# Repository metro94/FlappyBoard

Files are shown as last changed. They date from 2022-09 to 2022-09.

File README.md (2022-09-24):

[中文](README_zh.md) | English

# FlappyBoard

## Introduction

A minimum development board for CH32V203G6. The goal is simplicity, convenience and low-cost.

## 3D Rendering View

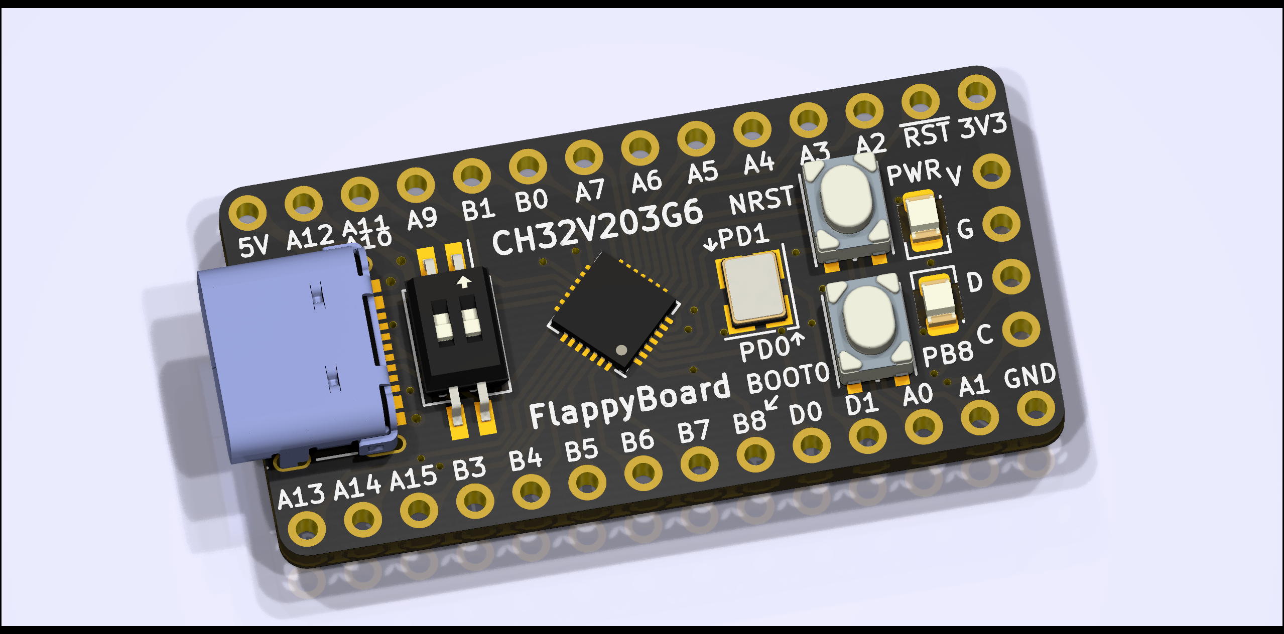
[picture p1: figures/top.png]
Top View


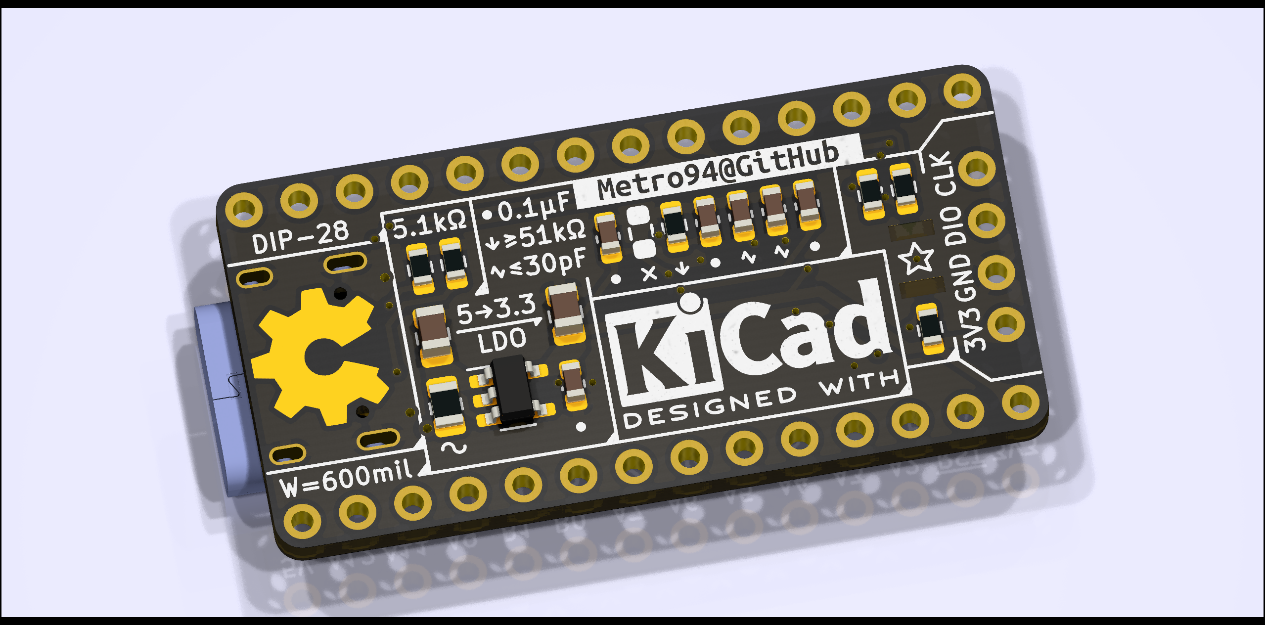
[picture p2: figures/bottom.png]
Bottom View


## License

[CERN-OHL-P](LICENSE)

## EDA

KiCad 6.0.6

## Usages

### Download Programs

It's simple and convenient to use USB download of [WCHISPTool](http://www.wch-ic.com/downloads/WCHISPTool_Setup_exe.html). Also serial download and debug port download is available.

WCHISTool requires correct MCU model (CH32V203) to download. The DIP switch shall be ON for downloading, and power the board with BOOT0 button pushed. If everything goes well, WCHISPTool shall report the MCU.

### LEDs and Buttons

There are two LEDs on the board, including *PWR* for power status (3.3V powered) and *PB8* for user-defined LED.

There are two buttons on the board, including *NRST* for system reset and *BOOT0* for boot mode (the default is to run user program in Flash, and push button to run bootloader in ROM).

> Note: In CH32V203G6, *PB8* and *BOOT0* is multiplexed. The behavior of this pin is:
>
> * When booting, MCU requires *BOOT0* status via this pin, and this pin is input. When *BOOT0* button is pushed, the LED of *PB8* is lighted to hint.
> * After entering user program, the *PB8* pin is available for output only, and the input value is invalid. Now, the LED of *PB8* can be controlled by user program, but the status of *BOOT0* button cannot be read.

### External Clock Input

CH32V203G6 can accept external oscillator and crystal. The valid frequency range is 3-25MHz.

### Schematics

[FlappyBoard Schematic](schematics/FlappyBoard.pdf)

### BOM

[FlappyBoard BOM](https://metro94.github.io/FlappyBoard/bom.html)

### Examples

[software/examples](software/examples)

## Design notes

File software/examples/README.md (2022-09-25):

# Examples for CH32V203G6

These examples are tested for FlappyBoard, and shall work for other CH32V203G6 boards.

> Note: WCHISPTool requires hex file to use CRLF as EOL.

*EVT* refers to [CH32V20xEVT.zip](https://www.wch.cn/downloads/CH32V20xEVT_ZIP.html), which contains source code of the most examples. [MounRiver Studio](http://www.mounriver.com/) or its toolchains can be used to compile source code.

> Note: These examples use *USART1* (*PA9*) as debug port with 115200n8 by default.

## CH372Device_D_FS

Compiled directly from `EVT/EXAM/USB/USBD/CH372Device`.

## CompositeKM

Modified from `EVT/EXAM/USB/USBD/CompositeKM`, use *PA2/PA3* as USART2 TX/RX.

## LED_Toggle

Modified from `EVT/EXAM/GPIO/GPIO_Toggle`, use PB8 LED and blink per 1 second.

## TinyMaix

TinyMaix demo for CH32V203G6. Please refer [CH32V203-TinyMaix](https://github.com/metro94/CH32V203-TinyMaix) or [TinyMaix](https://github.com/sipeed/TinyMaix) to get more information.

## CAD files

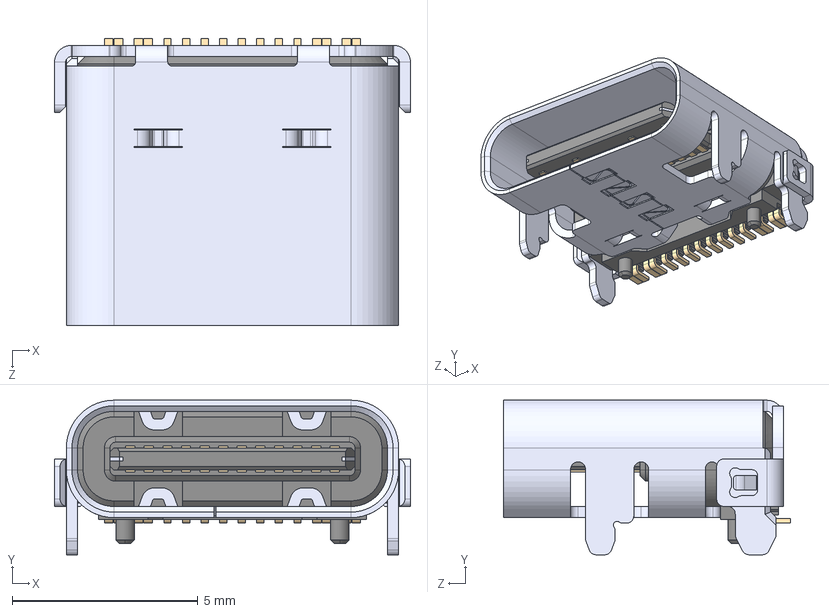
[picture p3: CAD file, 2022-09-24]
hardware/USB4105_GF_A.STEP
9.58 x 4.16 x 7.71 mm

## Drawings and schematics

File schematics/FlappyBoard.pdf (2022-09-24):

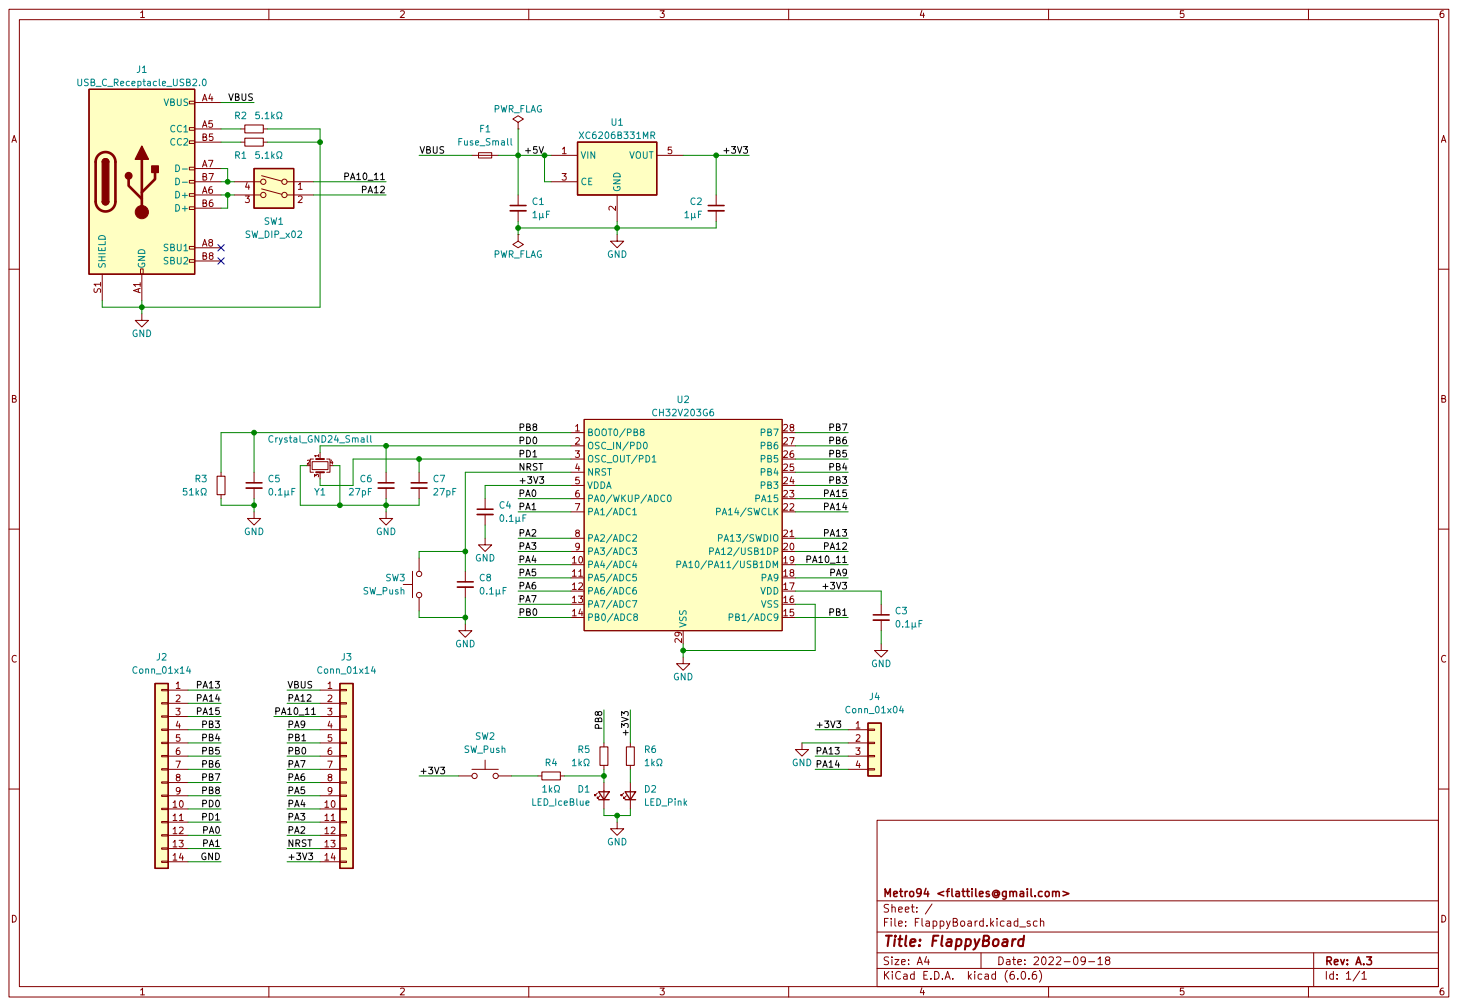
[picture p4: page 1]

File: FlappyBoard.kicad_sch Sheet: / Metro94 <flattiles@gmail.com>

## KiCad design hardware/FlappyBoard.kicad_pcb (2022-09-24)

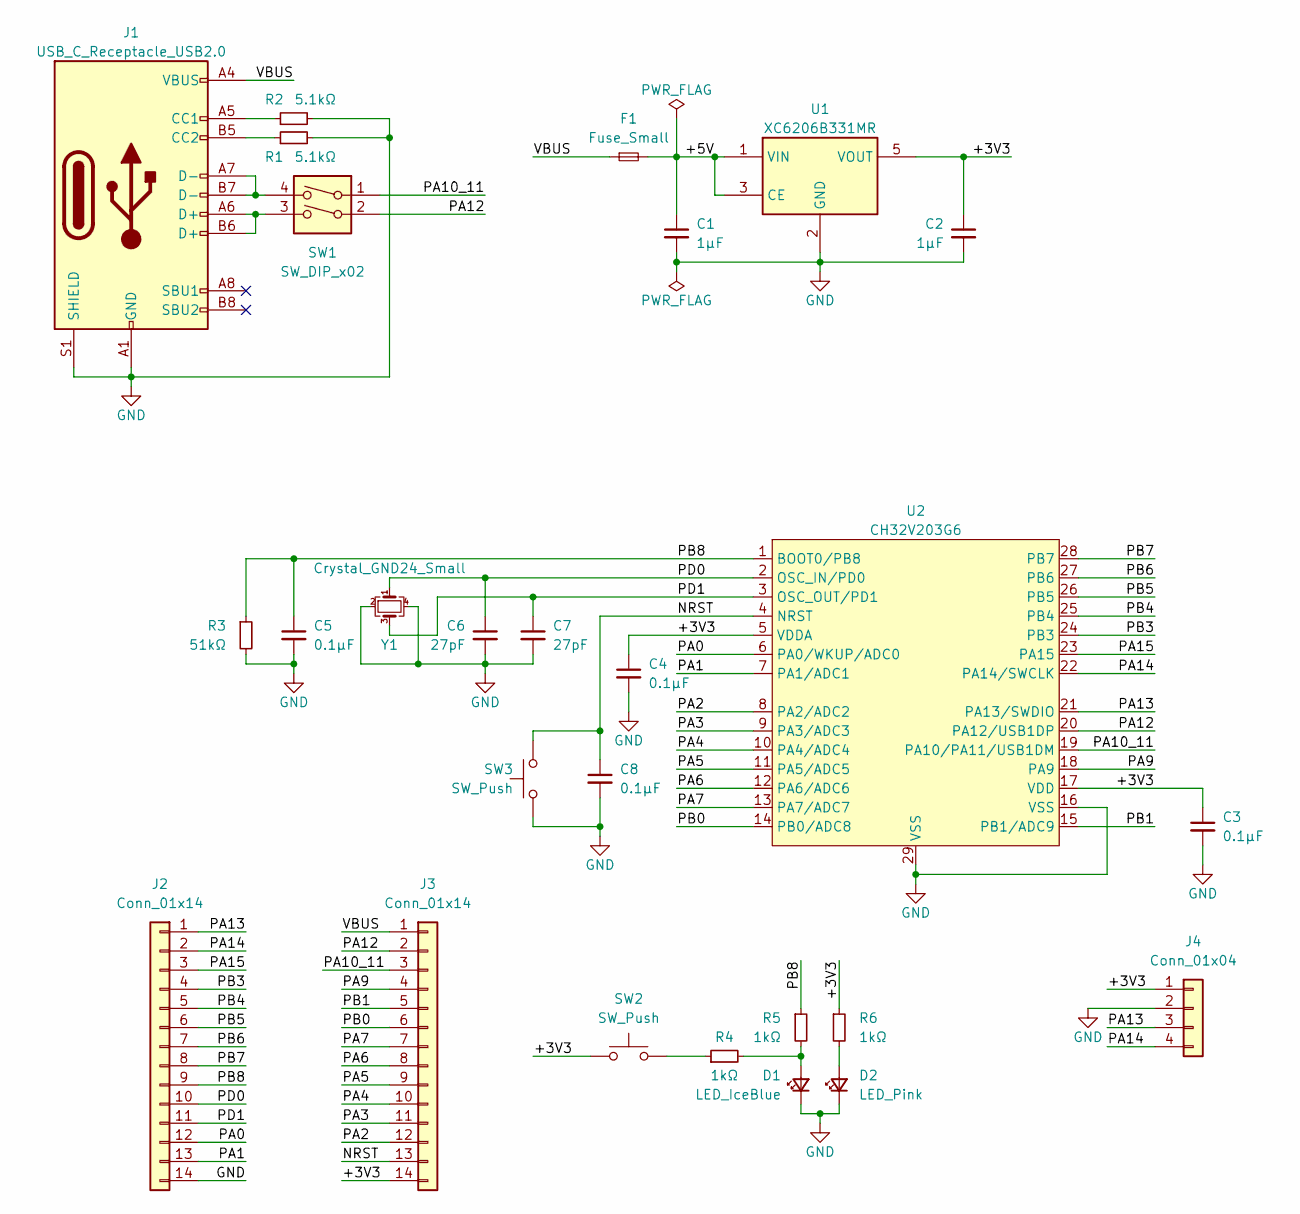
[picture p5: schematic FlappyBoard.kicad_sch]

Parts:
C1, C2: 1μF; C_0805_2012Metric; LCSC C28323
C3, C4, C5, C8: 0.1μF; C_0603_1608Metric; LCSC C14663
C6, C7: 27pF; C_0603_1608Metric
D1: LED_IceBlue; LED_0805_2012Metric; LCSC C2892177
D2: LED_Pink; LED_0805_2012Metric; LCSC C2892178
F1: Fuse_Small; Fuse_0805_2012Metric; LCSC C116170
J1: USB_C_Receptacle_USB2.0; USB_C_Receptacle_Palconn_UTC16-G; LCSC C963370
J2, J3: Conn_01x14; Pin_1x14_P2.54mm
J4: Conn_01x04; Pin_1x04_P2.54mm
R1, R2: 5.1kΩ; R_0603_1608Metric; LCSC C23186
R3: 51kΩ; R_0603_1608Metric; LCSC C23196
R4, R5, R6: 1kΩ; R_0603_1608Metric; LCSC C21190
SW1: SW_DIP_x02; SW_DIP_SPSTx02_Slide_Copal_CHS-02B_W7.62mm_P1.27mm; LCSC C3293142
SW2, SW3: SW_Push; SW_Push_1P1T_NO_Vertical_Wuerth_434133025816; LCSC C2888884
U1: XC6206B331MR; SOT-23-5; LCSC C82942
U2: CH32V203G6; QFN-28-1EP_4x4mm_P0.4mm_EP2.3x2.3mm; LCSC C5142280
Y1: Crystal_GND24_Small; Crystal_SMD_3225-4Pin_3.2x2.5mm

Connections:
/+3V3: C2.1, C3.1, C4.1, J3.14, J4.1, R6.1, SW2.1, U1.5 (VOUT), U2.5 (VDDA), U2.17 (VDD)
/+5V: C1.1, F1.2, U1.1 (VIN), U1.3 (CE)
/NRST: C8.1, J3.13, SW3.2, U2.4 (NRST)
/PA0: J2.12, U2.6 (PA0/WKUP/ADC0)
/PA1: J2.13, U2.7 (PA1/ADC1)
/PA2: J3.12, U2.8 (PA2/ADC2)
/PA3: J3.11, U2.9 (PA3/ADC3)
/PA4: J3.10, U2.10 (PA4/ADC4)
/PA5: J3.9, U2.11 (PA5/ADC5)
/PA6: J3.8, U2.12 (PA6/ADC6)
/PA7: J3.7, U2.13 (PA7/ADC7)
/PA9: J3.4, U2.18 (PA9)
/PA10_11: J3.3, SW1.1, U2.19 (PA10/PA11/USB1DM)
/PA12: J3.2, SW1.2, U2.20 (PA12/USB1DP)
/PA13: J2.1, J4.3, U2.21 (PA13/SWDIO)
/PA14: J2.2, J4.4, U2.22 (PA14/SWCLK)
/PA15: J2.3, U2.23 (PA15)
/PB0: J3.6, U2.14 (PB0/ADC8)
/PB1: J3.5, U2.15 (PB1/ADC9)
/PB3: J2.4, U2.24 (PB3)
/PB4: J2.5, U2.25 (PB4)
/PB5: J2.6, U2.26 (PB5)
/PB6: J2.7, U2.27 (PB6)
/PB7: J2.8, U2.28 (PB7)
/PB8: C5.1, J2.9, R3.1, R5.1, U2.1 (BOOT0/PB8)
/PD0: C6.1, J2.10, U2.2 (OSC_IN/PD0), Y1.1
/PD1: C7.1, J2.11, U2.3 (OSC_OUT/PD1), Y1.3
/VBUS: F1.1, J1.A4 (VBUS), J1.A9 (VBUS), J1.B4 (VBUS), J1.B9 (VBUS), J3.1
GND: C1.2, C2.2, C3.2, C4.2, C5.2, C6.2, C7.2, C8.2, D1.1 (K), D2.1 (K), J1.A1 (GND), J1.A12 (GND), J1.B1 (GND), J1.B12 (GND), J1.S1 (SHIELD), J2.14, J4.2, R1.2, R2.2, R3.2, SW3.1, U1.2 (GND), U2.16 (VSS), U2.29 (VSS), Y1.2, Y1.4
unnamed: D1.2 (A), R4.2, R5.2
unnamed: D2.2 (A), R6.2
unnamed: J1.A5 (CC1), R2.1
unnamed: J1.A6 (D+), J1.B6 (D+), SW1.3
unnamed: J1.A7 (D-), J1.B7 (D-), SW1.4
unnamed: J1.B5 (CC2), R1.1
unnamed: R4.1, SW2.2

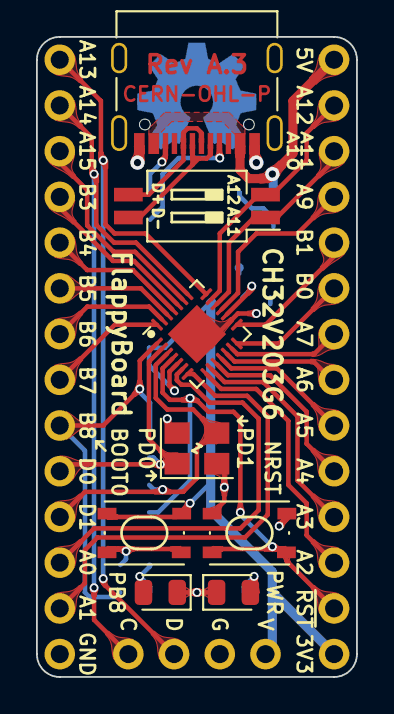
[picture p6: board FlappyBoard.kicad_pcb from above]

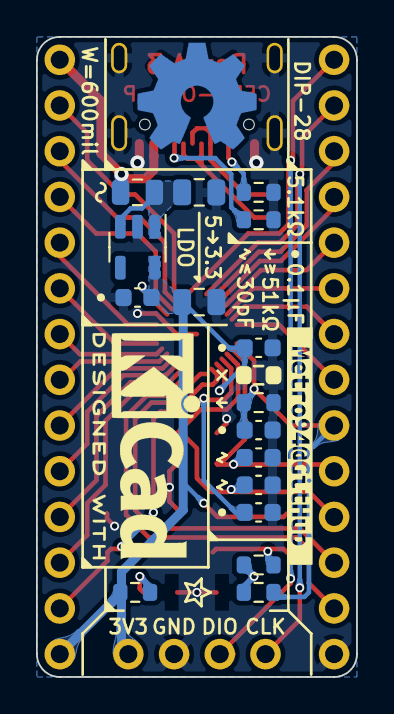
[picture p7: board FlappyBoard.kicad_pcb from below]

Board: 2 copper layers, 17.8 x 35.6 mm, 28 parts (17 on the bottom side), 36 nets.

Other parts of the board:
kibuzzard-6318E6BD: G***; kibuzzard-6318E6BD
